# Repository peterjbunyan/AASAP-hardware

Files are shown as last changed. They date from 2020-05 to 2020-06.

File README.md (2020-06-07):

# AASAP-hardware
KiCAD Schematics, PCBs and Gerbers for the AASAP computer's hardware.

The AASAP (Almost As Simple As Possible) computer is loosely based on the [8 bit breadboard computer](https://eater.net/8bit) built by Ben Eater which is turn was based on the SAP-1 (Simple As Possible - 1) design. The design of this computer builds on the knowledge from [Ben Eater's YouTube videos](https://www.youtube.com/playlist?list=PLowKtXNTBypGqImE405J2565dvjafglHU) but does not directly copy the design, and differs in a number of areas, the key ones being:

- Moving to a 16 bit address system for the internal RAM and the Program Counter.
- 32KB of RAM for program and data storage.
- 22 Control Bits to control input, output and special functions for each modules.
- A Wait line to halt the clock while waiting for external input.
- A Program line to disable the output of the control bits, allowing for external manual or automated writing of program data to RAM.
- Output to a 16x4 Character LCD.
- A modular PCB design based on individual cards that are linked together on a backplane PCB.

AASP Counting down from 4 to zero in a loop

Here you can see the almost complete AASAP running the following code to count down from 4 to zero:

    start:
      LDI 4     ; Load the A Register with an immediate value (4)
    loop:
      SUI 1     ; Subtract the immediate value (1) from the A Register
      JNZ loop  ; If the result was not zero, jump to loop
      JMP       ; Jump to start

The board connected at the top of the image is a bootloader based on an Arduino Nano. It can write to and read from RAM, and provides a clock for the AASAP.

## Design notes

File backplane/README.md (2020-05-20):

# AASAP backplane
This PCB is the backplane that connects all of the computers modules together. It can be chained to other modules using IDC cables, which is necessary to add the number of module required for the computer to function

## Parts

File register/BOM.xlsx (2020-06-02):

Manufacturer | MPN | Description | Value | Quantity | Part references
Multicomp Pro | MCFYU6104Z6 | Ceramic Capacitor | 0.1uF | 3 | C1..3
Multicomp Pro | MCL053PD | 5mm Light emitting diode - Red |  | 8 | D1..8
Multicomp Pro | 9339418 | 1/4W Through Hole Resistor | 330R | 8 | R1..8
Texas Instruments | SN74LS14N | Hex Inverter |  | 1 | U1
Texas Instruments | SN74LS173AN | 4-bit D-type Register, 3 state out |  | 2 | U2, U5
ST Microelectronics | ULN2803A | Darlington Transistor Arrays, DIP18 |  | 1 | U3
Texas Instruments | SN74LS541N | Buffer |  | 1 | U4
Amphenol ICC | DILB14P-223TLF | 14 Pin DIP Socket - 7.62mm |  | 1 | U1
Amphenol ICC | DILB16P223TLF | 16 Pin DIP Socket - 7.62mm |  | 2 | U2, U5
Amphenol ICC | DILB18P223TLF | 18 Pin DIP Socket - 7.62mm |  | 1 | U3
Amphenol ICC | DILB20P-223TLF | 20 Pin DIP Socket - 7.62mm |  | 1 | U4

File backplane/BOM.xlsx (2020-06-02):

Manufacturer | MPN | Description | Quantity | Part references
TE Connectivity | 5530843-8 | Standard Edge II Connector - 72 Position | 5 | J2..6
Multicomp Pro | MC-254-50-00-ST-DIP | 2.54mm Shrouded IDC connector, 2x25 Contacts | 2 | J1, J7
TE Connectivity | 1-1825002-3 | DIP Switch - 8 Way | 5 | SW1..5
JST | LC-04T | 4 Way Shrouded Header, Top Entry | 1 | J8

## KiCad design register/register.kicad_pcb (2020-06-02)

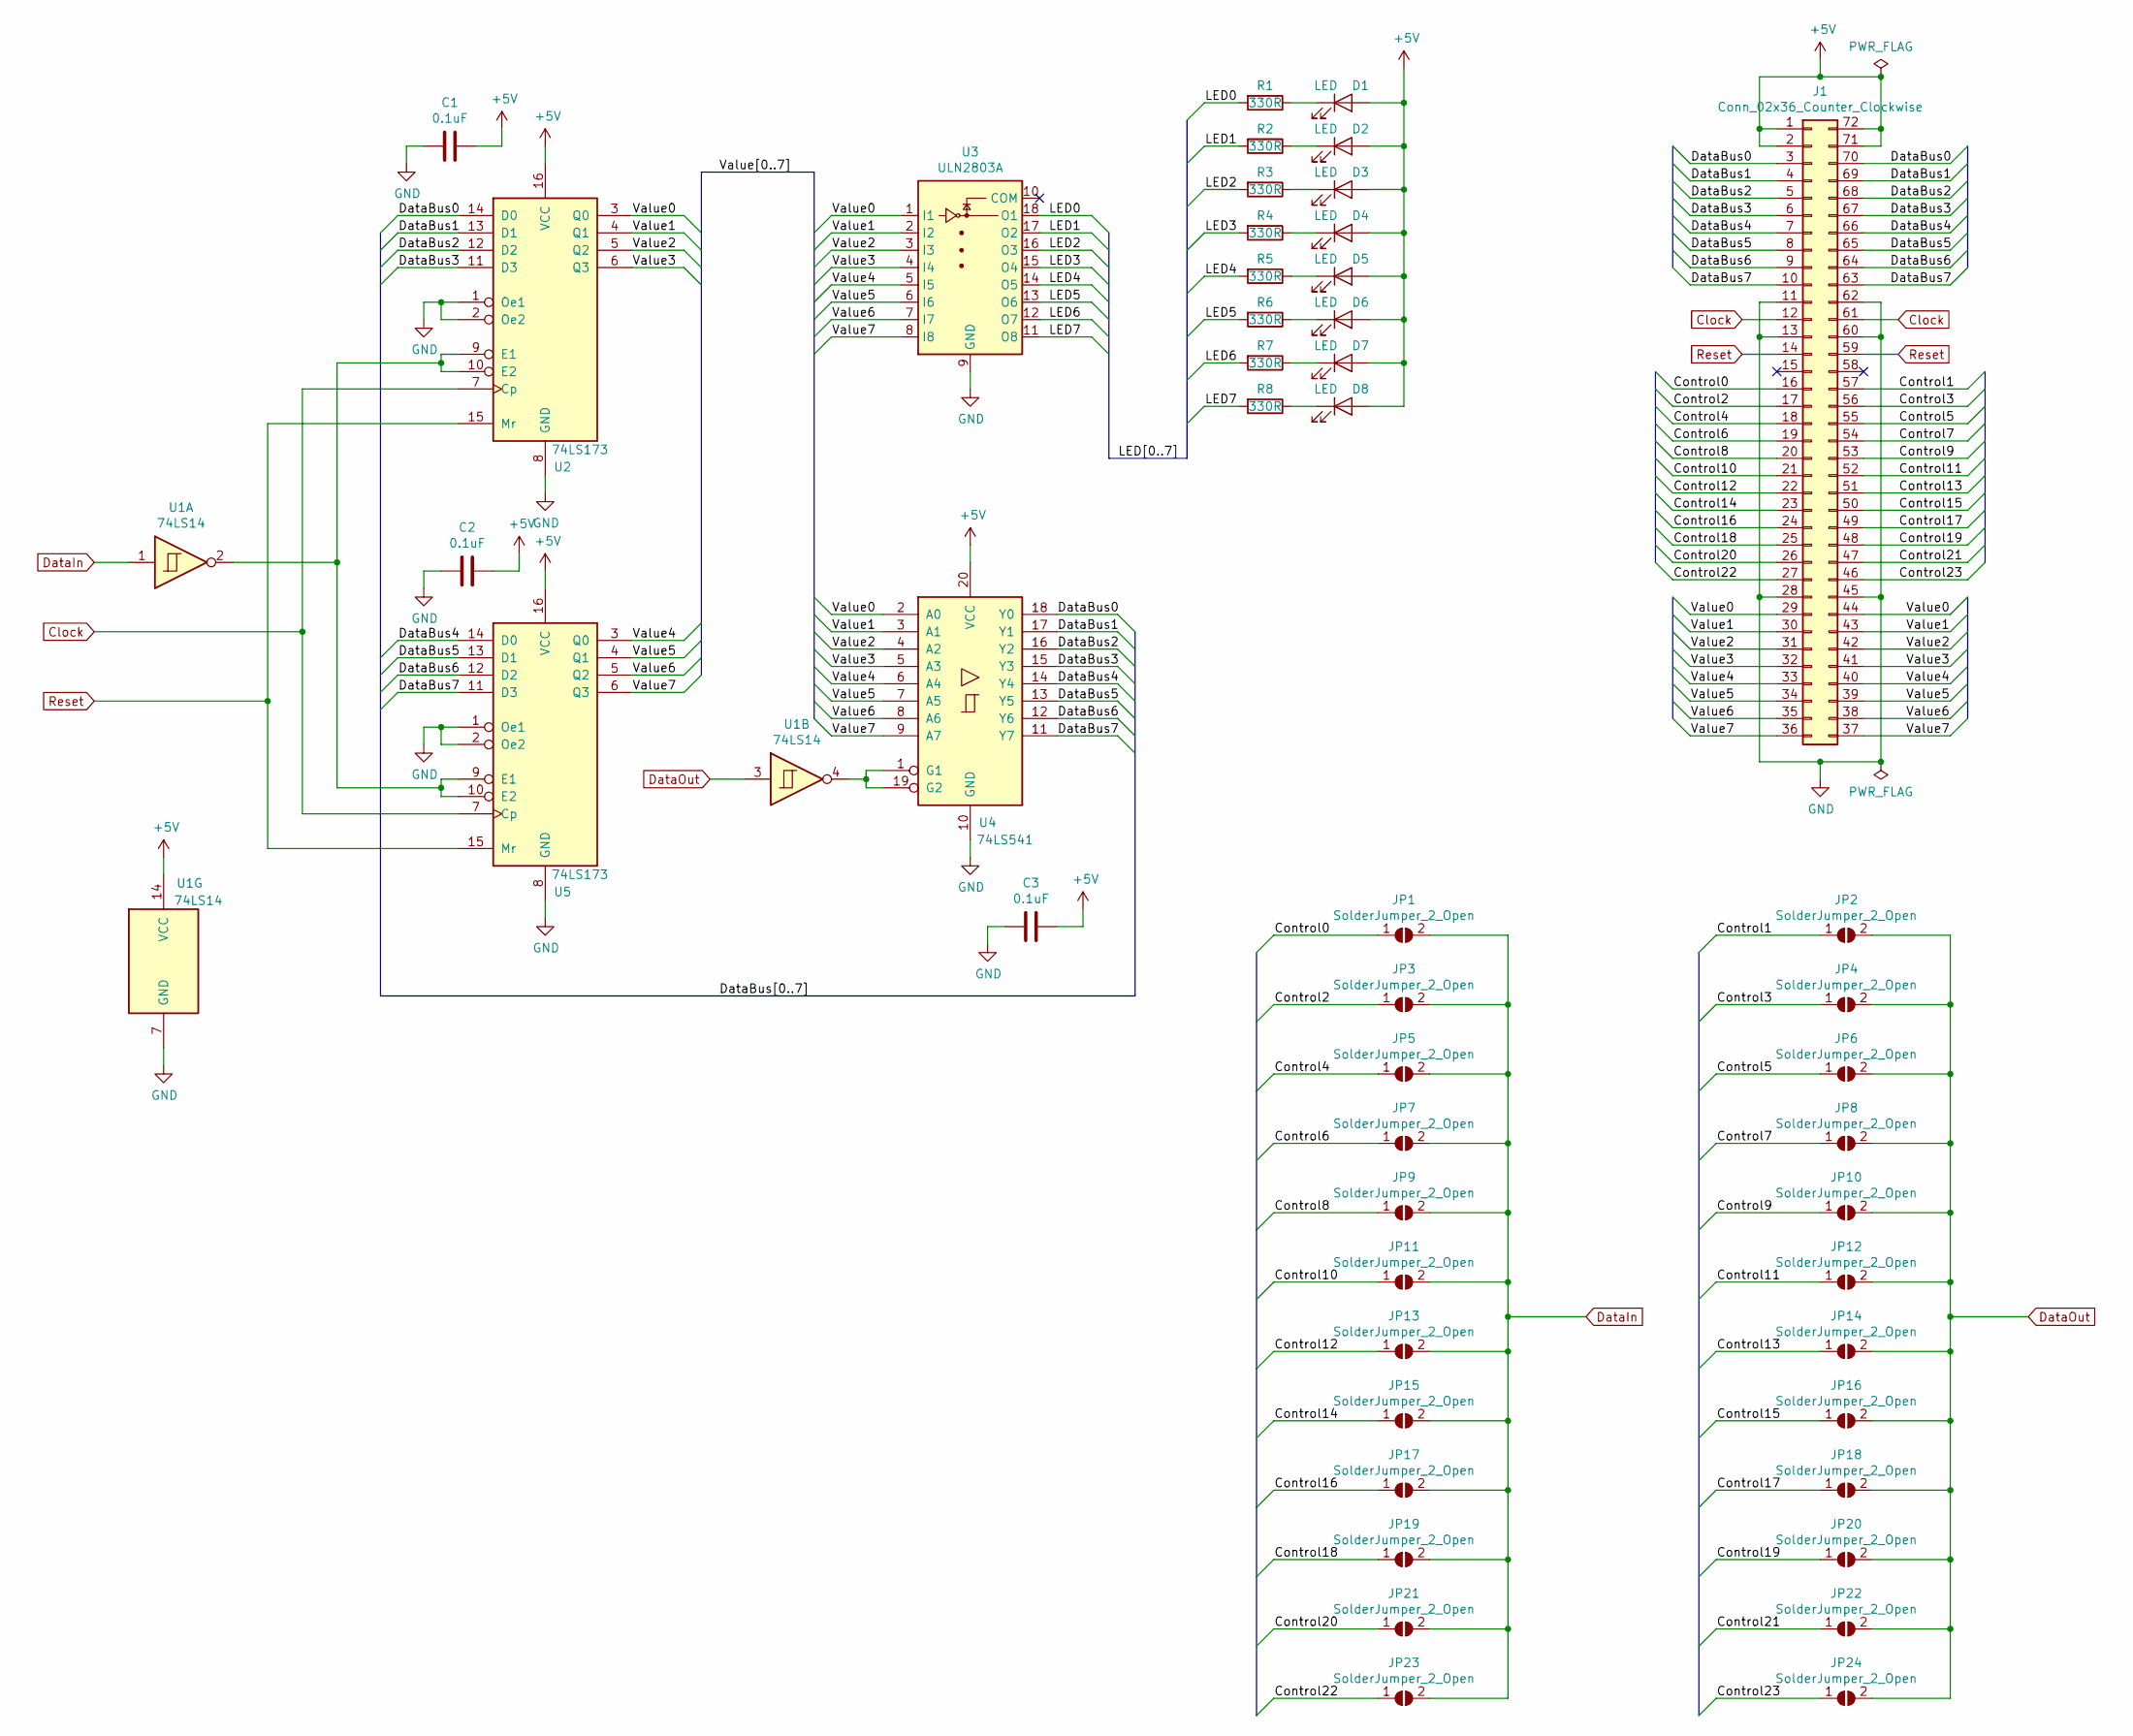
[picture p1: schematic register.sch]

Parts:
C1, C2, C3: 0.1uF; C_Disc_D6.0mm_W2.5mm_P5.00mm
D1, D2, D3, D4, D5, D6, D7, D8: LED; LED_D5.0mm_Horizontal_O1.27mm_Z3.0mm
J1: Conn_02x36_Counter_Clockwise; Standard_Edge_II_72_POS_PCB
JP1, JP2, JP3, JP4, JP5, JP6, JP7, JP8, JP9, JP10, JP11, JP12, JP13, JP14, JP15, JP16, JP17, JP18, JP19, JP20, JP21, JP22, JP23, JP24: SolderJumper_2_Open; SolderJumper-2_P1.3mm_Open_TrianglePad1.0x1.5mm
R1, R2, R3, R4, R5, R6, R7, R8: 330R; R_Axial_DIN0204_L3.6mm_D1.6mm_P7.62mm_Horizontal
U1: 74LS14; DIP-14_W7.62mm_Socket
U2, U5: 74LS173; DIP-16_W7.62mm_Socket
U3: ULN2803A; DIP-18_W7.62mm_Socket
U4: 74LS541; DIP-20_W7.62mm_Socket

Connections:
+5V: C1.1, C2.1, C3.1, D1.2 (A), D2.2 (A), D3.2 (A), D4.2 (A), D5.2 (A), D6.2 (A), D7.2 (A), D8.2 (A), J1.1, J1.2, J1.71, J1.72, U1.14 (VCC), U2.16 (VCC), U4.20 (VCC), U5.16 (VCC)
/Control0: J1.16, JP1.1 (A)
/Control1: J1.57, JP2.1 (A)
/Control2: J1.17, JP3.1 (A)
/Control3: J1.56, JP4.1 (A)
/Control4: J1.18, JP5.1 (A)
/Control5: J1.55, JP6.1 (A)
/Control6: J1.19, JP7.1 (A)
/Control7: J1.54, JP8.1 (A)
/Control8: J1.20, JP9.1 (A)
/Control9: J1.53, JP10.1 (A)
/Control10: J1.21, JP11.1 (A)
/Control11: J1.52, JP12.1 (A)
/Control12: J1.22, JP13.1 (A)
/Control13: J1.51, JP14.1 (A)
/Control14: J1.23, JP15.1 (A)
/Control15: J1.50, JP16.1 (A)
/Control16: J1.24, JP17.1 (A)
/Control17: J1.49, JP18.1 (A)
/Control18: J1.25, JP19.1 (A)
/Control19: J1.48, JP20.1 (A)
/Control20: J1.26, JP21.1 (A)
/Control21: J1.47, JP22.1 (A)
/Control22: J1.27, JP23.1 (A)
/Control23: J1.46, JP24.1 (A)
/DataBus0: J1.3, J1.70, U2.14 (D0), U4.18 (Y0)
/DataBus1: J1.4, J1.69, U2.13 (D1), U4.17 (Y1)
/DataBus2: J1.5, J1.68, U2.12 (D2), U4.16 (Y2)
/DataBus3: J1.6, J1.67, U2.11 (D3), U4.15 (Y3)
/DataBus4: J1.7, J1.66, U4.14 (Y4), U5.14 (D0)
/DataBus5: J1.8, J1.65, U4.13 (Y5), U5.13 (D1)
/DataBus6: J1.9, J1.64, U4.12 (Y6), U5.12 (D2)
/DataBus7: J1.10, J1.63, U4.11 (Y7), U5.11 (D3)
/LED0: R1.2, U3.18 (O1)
/LED1: R2.2, U3.17 (O2)
/LED2: R3.2, U3.16 (O3)
/LED3: R4.2, U3.15 (O4)
/LED4: R5.2, U3.14 (O5)
/LED5: R6.2, U3.13 (O6)
/LED6: R7.2, U3.12 (O7)
/LED7: R8.2, U3.11 (O8)
/Value0: J1.29, J1.44, U2.3 (Q0), U3.1 (I1), U4.2 (A0)
/Value1: J1.30, J1.43, U2.4 (Q1), U3.2 (I2), U4.3 (A1)
/Value2: J1.31, J1.42, U2.5 (Q2), U3.3 (I3), U4.4 (A2)
/Value3: J1.32, J1.41, U2.6 (Q3), U3.4 (I4), U4.5 (A3)
/Value4: J1.33, J1.40, U3.5 (I5), U4.6 (A4), U5.3 (Q0)
/Value5: J1.34, J1.39, U3.6 (I6), U4.7 (A5), U5.4 (Q1)
/Value6: J1.35, J1.38, U3.7 (I7), U4.8 (A6), U5.5 (Q2)
/Value7: J1.36, J1.37, U3.8 (I8), U4.9 (A7), U5.6 (Q3)
Clock: J1.12, J1.61, U2.7 (Cp), U5.7 (Cp)
DataIn: JP1.2 (B), JP3.2 (B), JP5.2 (B), JP7.2 (B), JP9.2 (B), JP11.2 (B), JP13.2 (B), JP15.2 (B), JP17.2 (B), JP19.2 (B), JP21.2 (B), JP23.2 (B), U1.1
DataOut: JP2.2 (B), JP4.2 (B), JP6.2 (B), JP8.2 (B), JP10.2 (B), JP12.2 (B), JP14.2 (B), JP16.2 (B), JP18.2 (B), JP20.2 (B), JP22.2 (B), JP24.2 (B), U1.3
GND: C1.2, C2.2, C3.2, J1.11, J1.13, J1.28, J1.45, J1.60, J1.62, U1.7 (GND), U2.1 (Oe1), U2.2 (Oe2), U2.8 (GND), U3.9 (GND), U4.10 (GND), U5.1 (Oe1), U5.2 (Oe2), U5.8 (GND)
unnamed: D1.1 (K), R1.1
unnamed: D2.1 (K), R2.1
unnamed: D3.1 (K), R3.1
unnamed: D4.1 (K), R4.1
unnamed: D5.1 (K), R5.1
unnamed: D6.1 (K), R6.1
unnamed: D7.1 (K), R7.1
unnamed: D8.1 (K), R8.1
unnamed: U1.2, U2.9 (E1), U2.10 (E2), U5.9 (E1), U5.10 (E2)
unnamed: U1.4, U4.1 (G1), U4.19 (G2)
Reset: J1.14, J1.59, U2.15 (Mr), U5.15 (Mr)

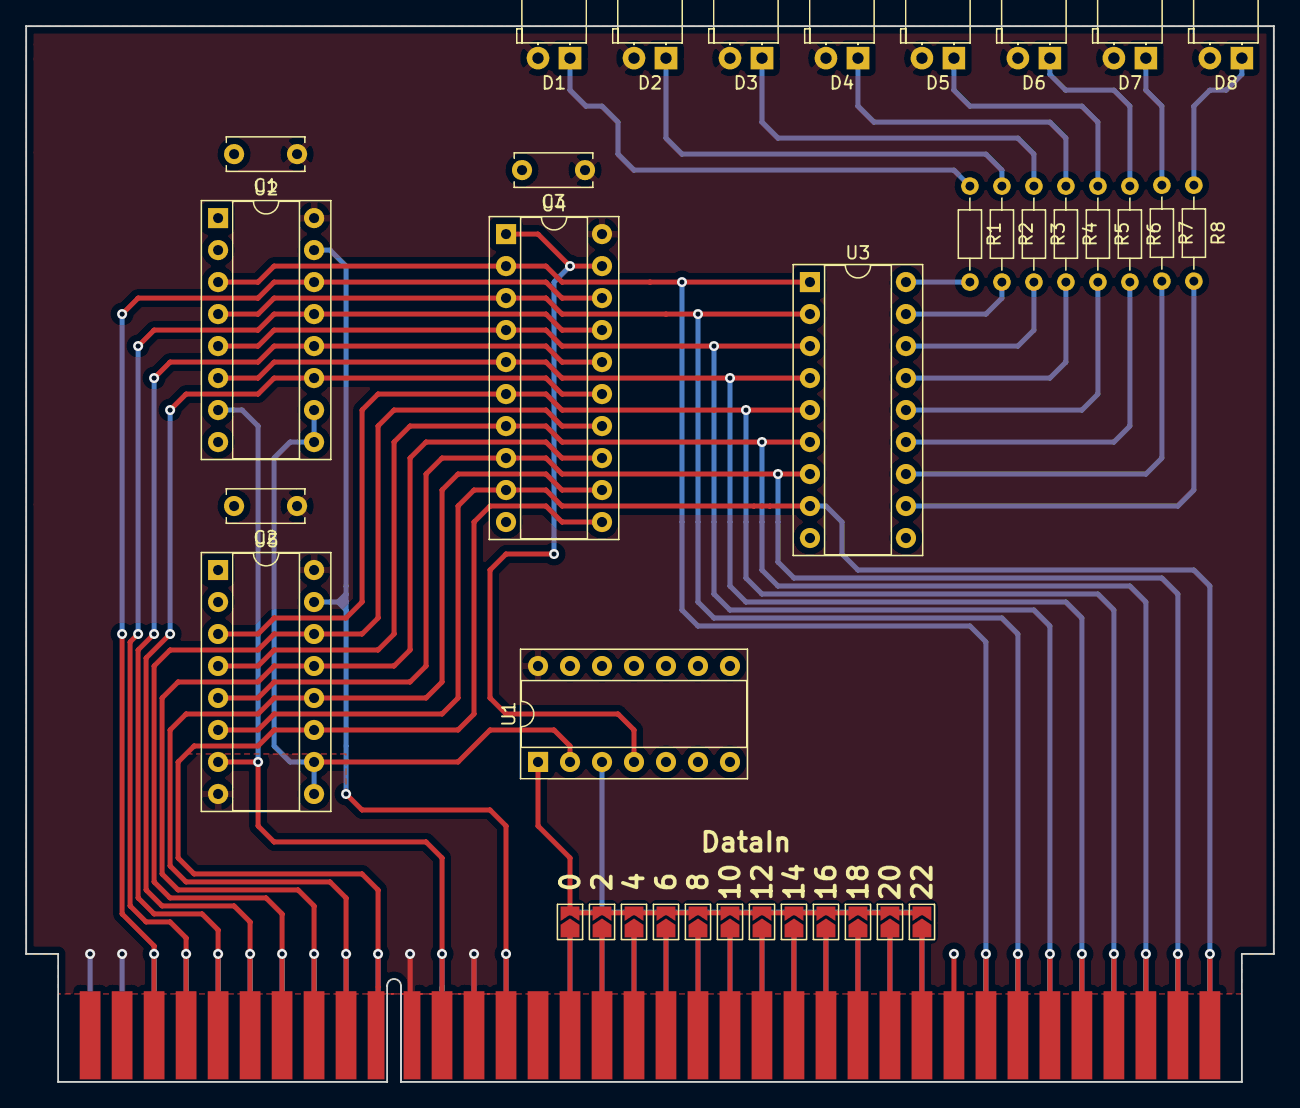
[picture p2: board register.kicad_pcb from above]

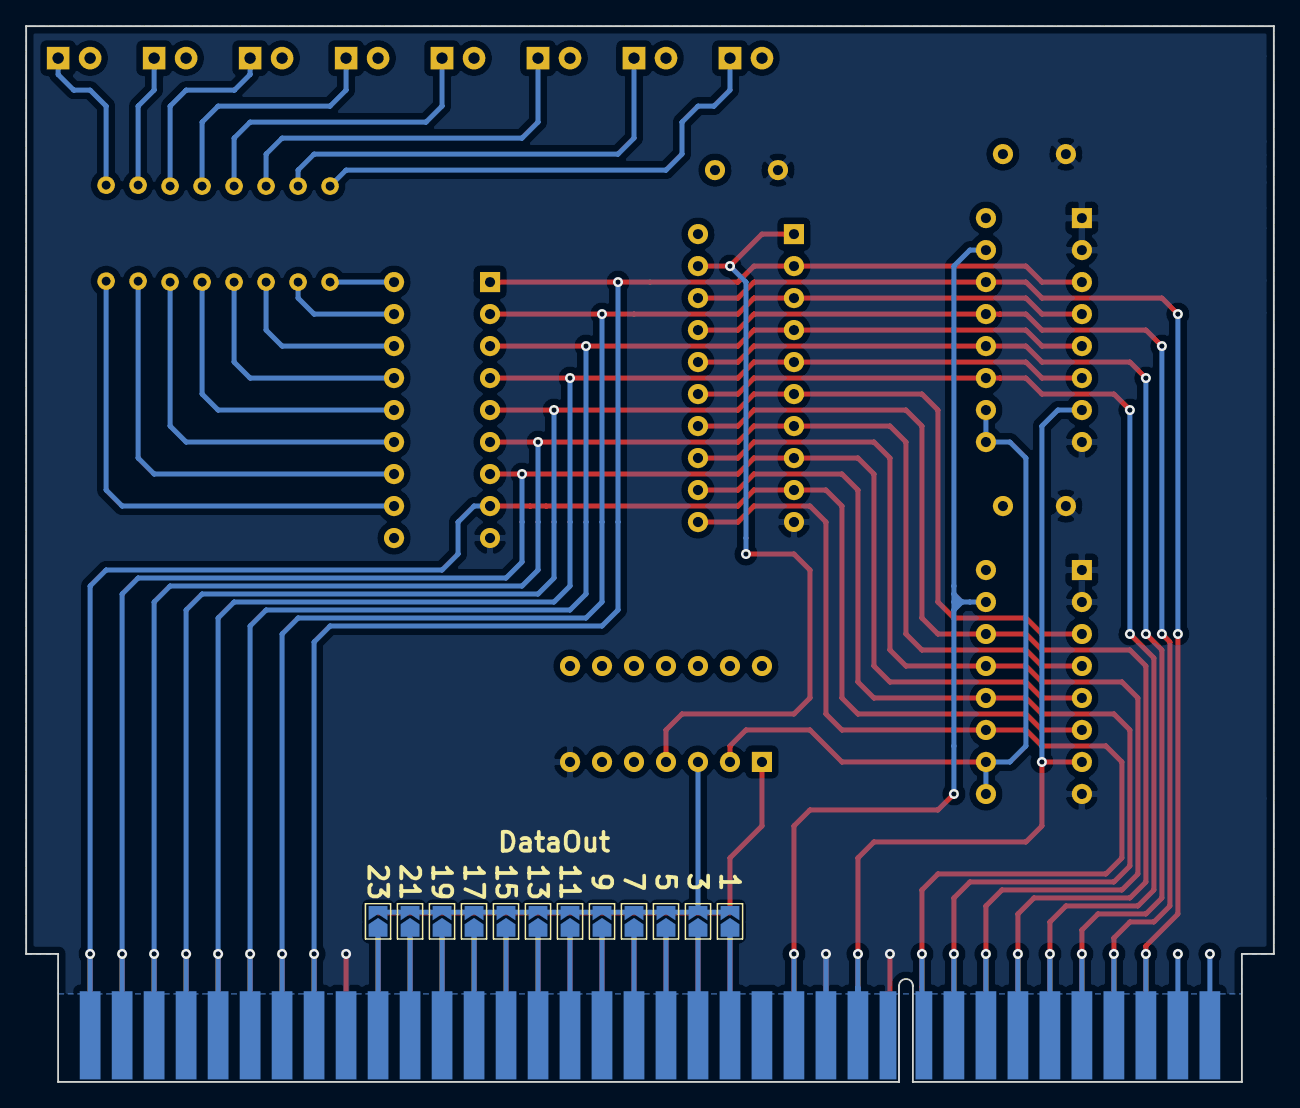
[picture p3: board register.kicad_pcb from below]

Board: 2 copper layers, 99.1 x 83.8 mm, 49 parts (12 on the bottom side), 64 nets.

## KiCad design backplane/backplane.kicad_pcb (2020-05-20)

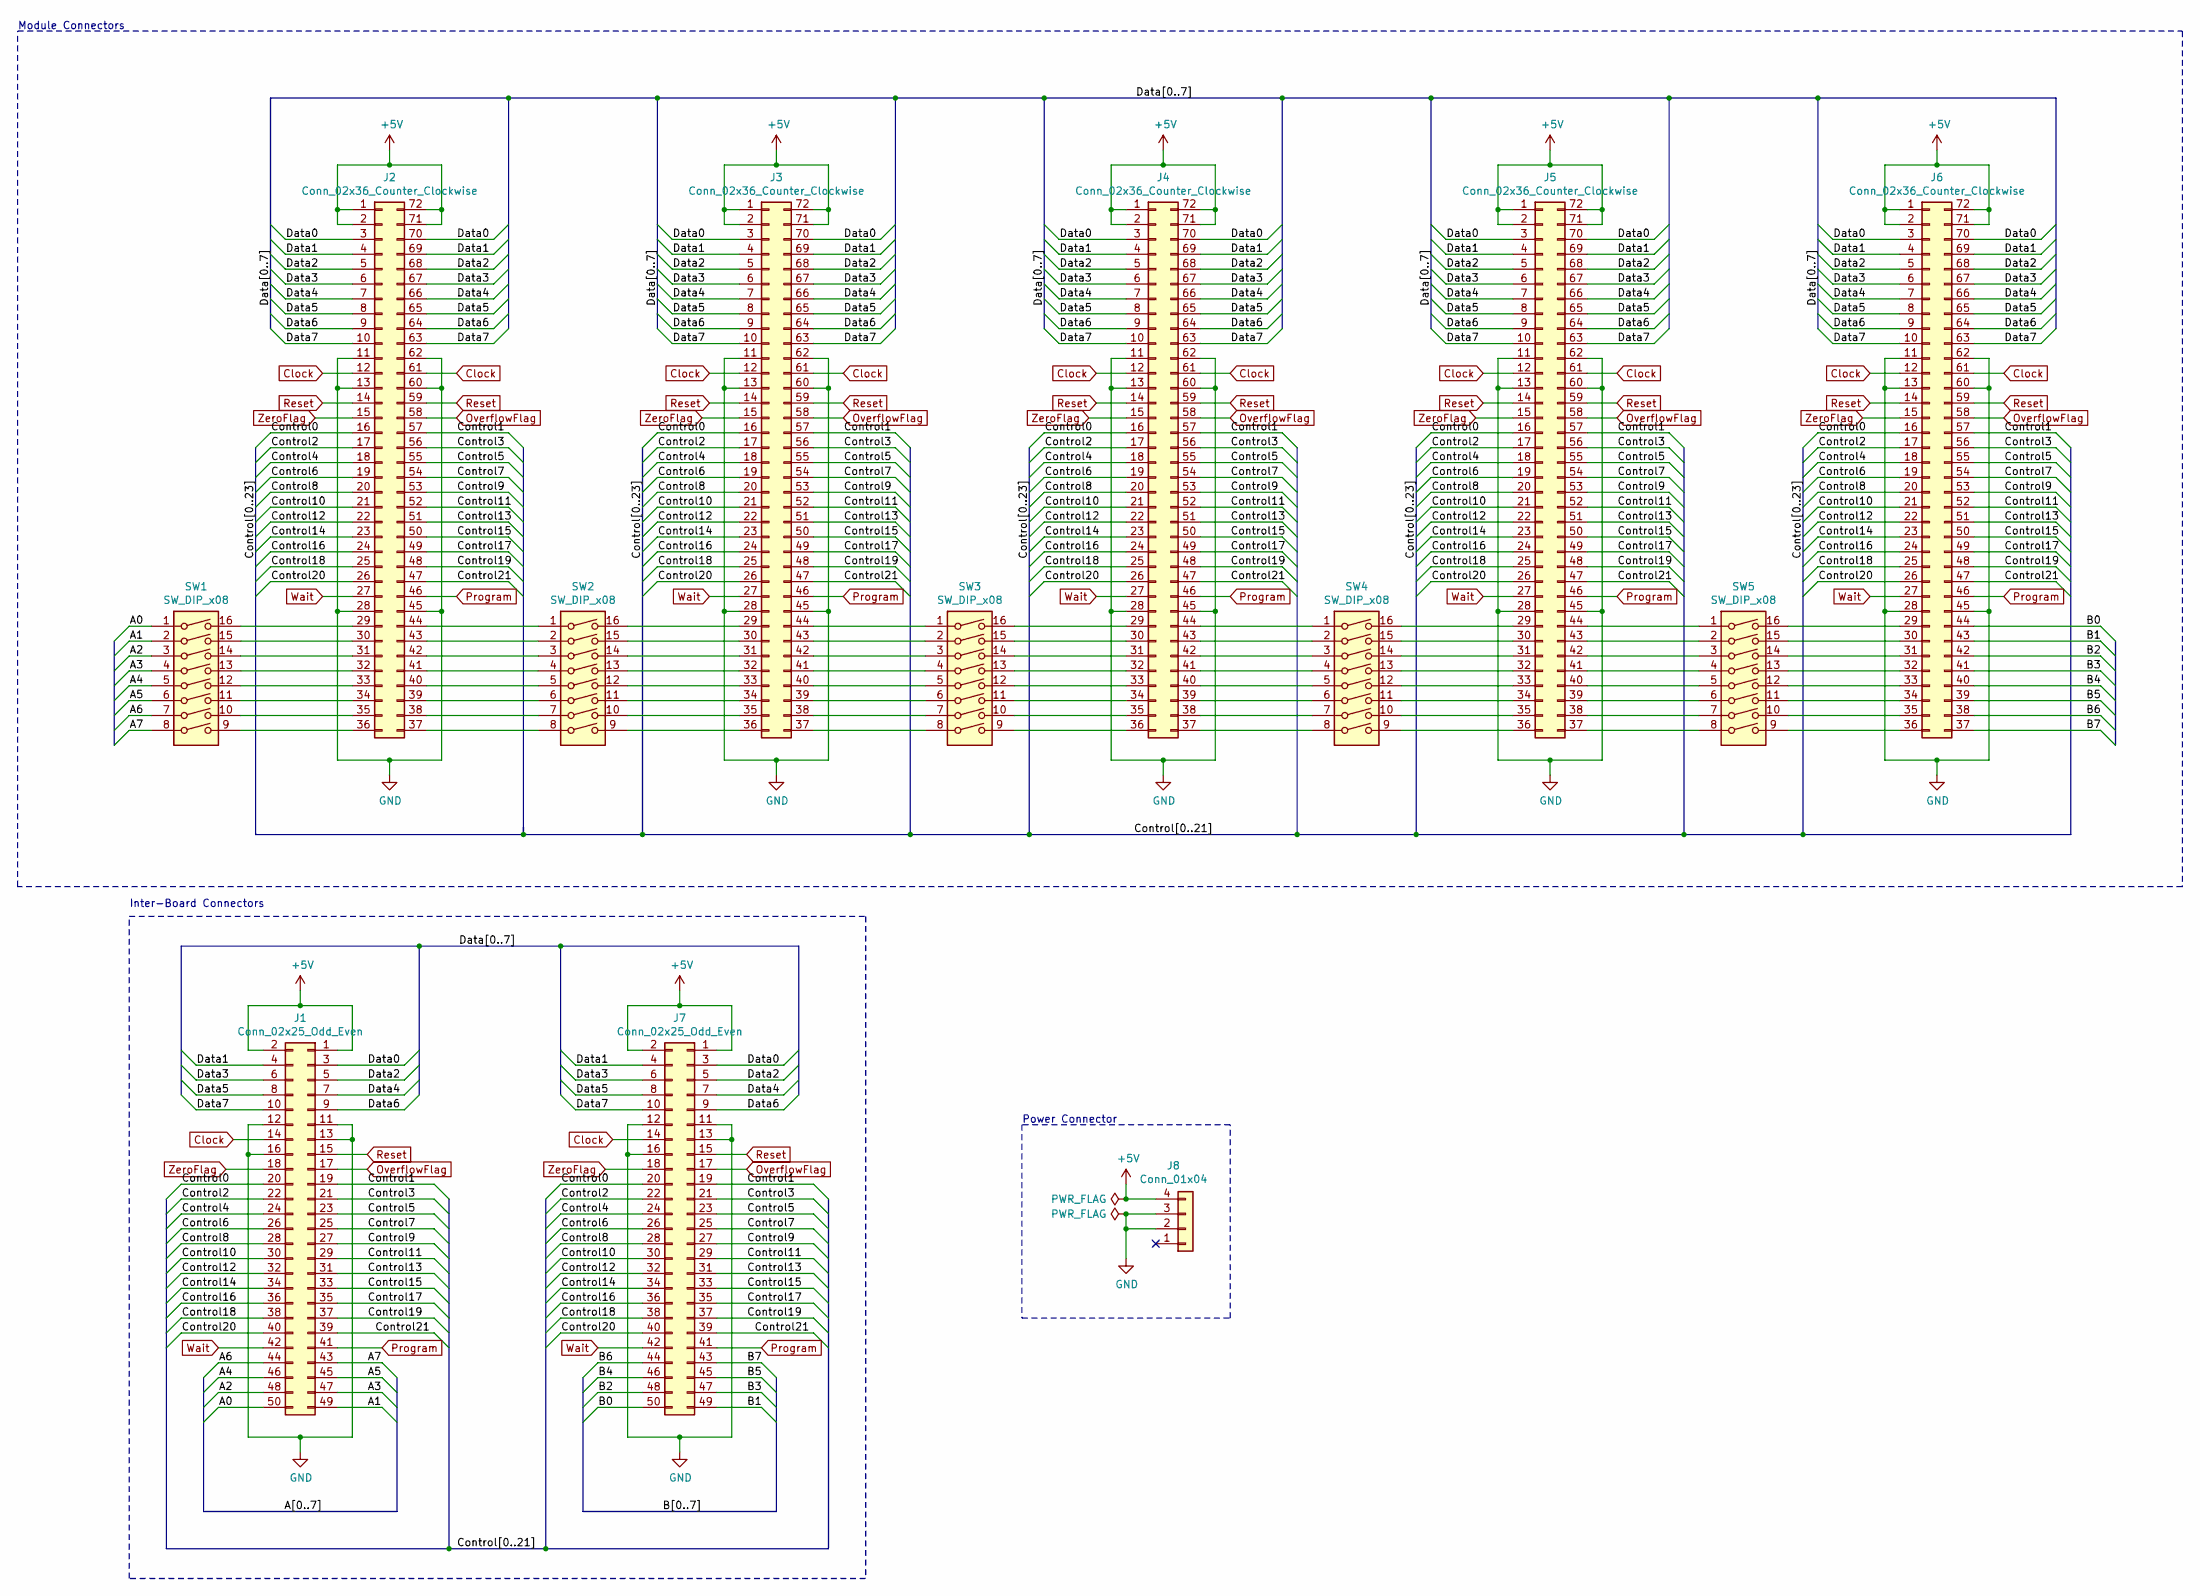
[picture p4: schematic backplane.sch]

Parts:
J1, J7: Conn_02x25_Odd_Even; Multicomp_MC9A12-5034_2x25_P2.54mm_Vertical
J2, J3, J4, J5, J6: Conn_02x36_Counter_Clockwise; Standard_Edge_II_72_POS
J8: Conn_01x04; TerminalBlock_bornier-4_P5.08mm
SW1, SW2, SW3, SW4, SW5: SW_DIP_x08; SW_DIP_SPSTx08_Slide_9.78x22.5mm_W7.62mm_P2.54mm

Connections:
+5V: J1.1, J1.2, J2.1, J2.2, J2.71, J2.72, J3.1, J3.2, J3.71, J3.72, J4.1, J4.2, J4.71, J4.72, J5.1, J5.2, J5.71, J5.72, J6.1, J6.2, J6.71, J6.72, J7.1, J7.2, J8.4
/A0: J1.50, SW1.1
/A1: J1.49, SW1.2
/A2: J1.48, SW1.3
/A3: J1.47, SW1.4
/A4: J1.46, SW1.5
/A5: J1.45, SW1.6
/A6: J1.44, SW1.7
/A7: J1.43, SW1.8
/B0: J6.44, J7.50
/B1: J6.43, J7.49
/B2: J6.42, J7.48
/B3: J6.41, J7.47
/B4: J6.40, J7.46
/B5: J6.39, J7.45
/B6: J6.38, J7.44
/B7: J6.37, J7.43
/Control0: J1.20, J2.16, J3.16, J4.16, J5.16, J6.16, J7.20
/Control1: J1.19, J2.57, J3.57, J4.57, J5.57, J6.57, J7.19
/Control2: J1.22, J2.17, J3.17, J4.17, J5.17, J6.17, J7.22
/Control3: J1.21, J2.56, J3.56, J4.56, J5.56, J6.56, J7.21
/Control4: J1.24, J2.18, J3.18, J4.18, J5.18, J6.18, J7.24
/Control5: J1.23, J2.55, J3.55, J4.55, J5.55, J6.55, J7.23
/Control6: J1.26, J2.19, J3.19, J4.19, J5.19, J6.19, J7.26
/Control7: J1.25, J2.54, J3.54, J4.54, J5.54, J6.54, J7.25
/Control8: J1.28, J2.20, J3.20, J4.20, J5.20, J6.20, J7.28
/Control9: J1.27, J2.53, J3.53, J4.53, J5.53, J6.53, J7.27
/Control10: J1.30, J2.21, J3.21, J4.21, J5.21, J6.21, J7.30
/Control11: J1.29, J2.52, J3.52, J4.52, J5.52, J6.52, J7.29
/Control12: J1.32, J2.22, J3.22, J4.22, J5.22, J6.22, J7.32
/Control13: J1.31, J2.51, J3.51, J4.51, J5.51, J6.51, J7.31
/Control14: J1.34, J2.23, J3.23, J4.23, J5.23, J6.23, J7.34
/Control15: J1.33, J2.50, J3.50, J4.50, J5.50, J6.50, J7.33
/Control16: J1.36, J2.24, J3.24, J4.24, J5.24, J6.24, J7.36
/Control17: J1.35, J2.49, J3.49, J4.49, J5.49, J6.49, J7.35
/Control18: J1.38, J2.25, J3.25, J4.25, J5.25, J6.25, J7.38
/Control19: J1.37, J2.48, J3.48, J4.48, J5.48, J6.48, J7.37
/Control20: J1.40, J2.26, J3.26, J4.26, J5.26, J6.26, J7.40
/Control21: J1.39, J2.47, J3.47, J4.47, J5.47, J6.47, J7.39
/Data0: J1.3, J2.3, J2.70, J3.3, J3.70, J4.3, J4.70, J5.3, J5.70, J6.3, J6.70, J7.3
/Data1: J1.4, J2.4, J2.69, J3.4, J3.69, J4.4, J4.69, J5.4, J5.69, J6.4, J6.69, J7.4
/Data2: J1.5, J2.5, J2.68, J3.5, J3.68, J4.5, J4.68, J5.5, J5.68, J6.5, J6.68, J7.5
/Data3: J1.6, J2.6, J2.67, J3.6, J3.67, J4.6, J4.67, J5.6, J5.67, J6.6, J6.67, J7.6
/Data4: J1.7, J2.7, J2.66, J3.7, J3.66, J4.7, J4.66, J5.7, J5.66, J6.7, J6.66, J7.7
/Data5: J1.8, J2.8, J2.65, J3.8, J3.65, J4.8, J4.65, J5.8, J5.65, J6.8, J6.65, J7.8
/Data6: J1.9, J2.9, J2.64, J3.9, J3.64, J4.9, J4.64, J5.9, J5.64, J6.9, J6.64, J7.9
/Data7: J1.10, J2.10, J2.63, J3.10, J3.63, J4.10, J4.63, J5.10, J5.63, J6.10, J6.63, J7.10
Clock: J1.14, J2.12, J2.61, J3.12, J3.61, J4.12, J4.61, J5.12, J5.61, J6.12, J6.61, J7.14
GND: J1.11, J1.12, J1.13, J1.16, J2.11, J2.13, J2.28, J2.45, J2.60, J2.62, J3.11, J3.13, J3.28, J3.45, J3.60, J3.62, J4.11, J4.13, J4.28, J4.45, J4.60, J4.62, J5.11, J5.13, J5.28, J5.45, J5.60, J5.62, J6.11, J6.13, J6.28, J6.45, J6.60, J6.62, J7.11, J7.12, J7.13, J7.16, J8.2, J8.3
unnamed: J2.29, SW1.16
unnamed: J2.30, SW1.15
unnamed: J2.31, SW1.14
unnamed: J2.32, SW1.13
unnamed: J2.33, SW1.12
unnamed: J2.34, SW1.11
unnamed: J2.35, SW1.10
unnamed: J2.36, SW1.9
unnamed: J2.37, SW2.8
unnamed: J2.38, SW2.7
unnamed: J2.39, SW2.6
unnamed: J2.40, SW2.5
unnamed: J2.41, SW2.4
unnamed: J2.42, SW2.3
unnamed: J2.43, SW2.2
unnamed: J2.44, SW2.1
unnamed: J3.29, SW2.16
unnamed: J3.30, SW2.15
unnamed: J3.31, SW2.14
unnamed: J3.32, SW2.13
unnamed: J3.33, SW2.12
unnamed: J3.34, SW2.11
unnamed: J3.35, SW2.10
unnamed: J3.36, SW2.9
unnamed: J3.37, SW3.8
unnamed: J3.38, SW3.7
unnamed: J3.39, SW3.6
unnamed: J3.40, SW3.5
unnamed: J3.41, SW3.4
unnamed: J3.42, SW3.3
unnamed: J3.43, SW3.2
unnamed: J3.44, SW3.1
unnamed: J4.29, SW3.16
unnamed: J4.30, SW3.15
unnamed: J4.31, SW3.14
unnamed: J4.32, SW3.13
unnamed: J4.33, SW3.12
unnamed: J4.34, SW3.11
unnamed: J4.35, SW3.10
unnamed: J4.36, SW3.9
unnamed: J4.37, SW4.8
unnamed: J4.38, SW4.7
unnamed: J4.39, SW4.6
unnamed: J4.40, SW4.5
unnamed: J4.41, SW4.4
unnamed: J4.42, SW4.3
unnamed: J4.43, SW4.2
unnamed: J4.44, SW4.1
unnamed: J5.29, SW4.16
unnamed: J5.30, SW4.15
unnamed: J5.31, SW4.14
unnamed: J5.32, SW4.13
unnamed: J5.33, SW4.12
unnamed: J5.34, SW4.11
unnamed: J5.35, SW4.10
unnamed: J5.36, SW4.9
unnamed: J5.37, SW5.8
unnamed: J5.38, SW5.7
unnamed: J5.39, SW5.6
unnamed: J5.40, SW5.5
unnamed: J5.41, SW5.4
unnamed: J5.42, SW5.3
unnamed: J5.43, SW5.2
unnamed: J5.44, SW5.1
unnamed: J6.29, SW5.16
unnamed: J6.30, SW5.15
unnamed: J6.31, SW5.14
unnamed: J6.32, SW5.13
unnamed: J6.33, SW5.12
unnamed: J6.34, SW5.11
unnamed: J6.35, SW5.10
unnamed: J6.36, SW5.9
OverflowFlag: J1.17, J2.58, J3.58, J4.58, J5.58, J6.58, J7.17
Program: J1.41, J2.46, J3.46, J4.46, J5.46, J6.46, J7.41
Reset: J1.15, J2.14, J2.59, J3.14, J3.59, J4.14, J4.59, J5.14, J5.59, J6.14, J6.59, J7.15
Wait: J1.42, J2.27, J3.27, J4.27, J5.27, J6.27, J7.42
ZeroFlag: J1.18, J2.15, J3.15, J4.15, J5.15, J6.15, J7.18

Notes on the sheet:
Inter-Board Connectors
Power Connector
Module Connectors

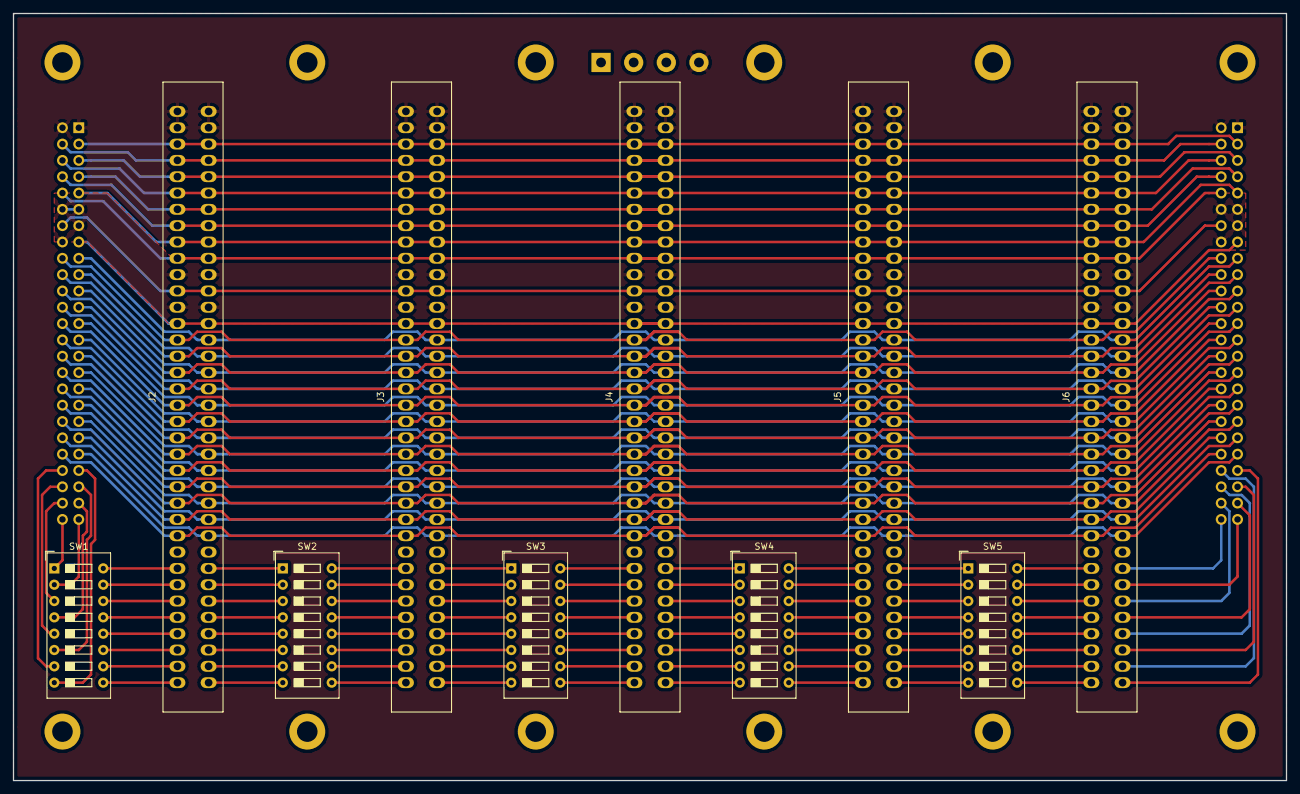
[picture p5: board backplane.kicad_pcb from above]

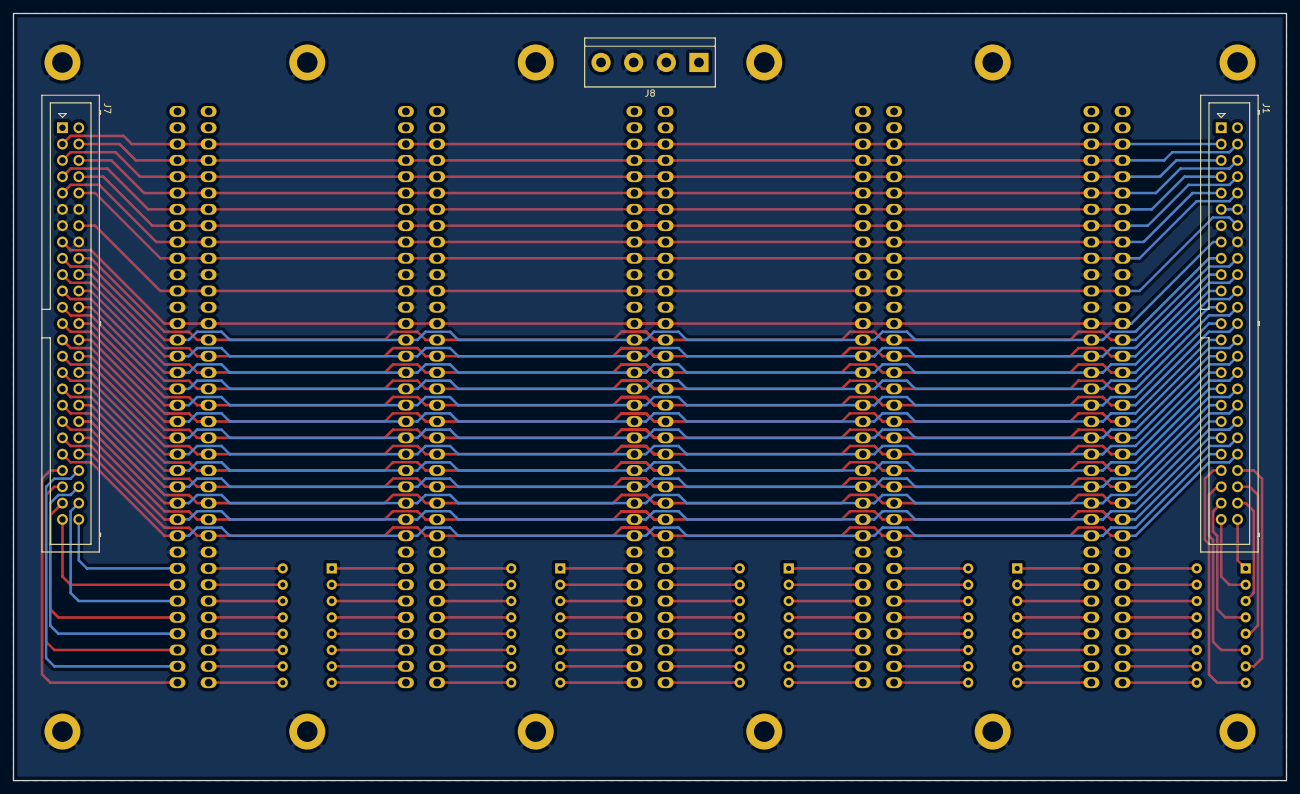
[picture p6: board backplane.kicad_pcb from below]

Board: 2 copper layers, 198.1 x 119.4 mm, 13 parts (3 on the bottom side), 126 nets.

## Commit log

2020-05-20 Initial Commit Initial commit with a basic README and files for the computer backplane
    [backplane-B.Cu.gbl, backplane-B.Mask.gbs, backplane-B.SilkS.gbo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]
2020-06-02 Added BOM for backplane
    [BOM.xlsx]
2020-06-02 Added Register Files
    [BOM.xlsx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]
2020-06-02 Added Component References to Register BOM
    [BOM.xlsx]
